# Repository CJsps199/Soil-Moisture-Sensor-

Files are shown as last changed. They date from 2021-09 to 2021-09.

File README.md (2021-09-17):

# Soil-Moisture-Sensor-
Soil Moisture sensor utilizing MCCI LMIC Library for LoRaWan© &amp; Chirpstack Network Server

# FOR SINGLE CHANNEL GATEWAY ONLY
Gateway & Sensor Node code.
Tweaked for my requirements.
# No Frequency Hopping.
# CAUTION
# NON "REGULATORY"
# USE AT OWN RISK
# Change each node's TX interval to best avoid conflict in receival on Gateway side

# Utilization of the great ChirpStack Network Server.
https://github.com/brocaar/chirpstack-network-server. (Thanks to Brocaar for this).

Using ESP8266 or ESP12F for the Gateway
Using Atmega 328P

See Eagle Drawings for compact Design of Sensor Node. +- 7cm x 4cm x 2cm.
Including MPPT Solar Charger CHIP. 
LiPo Battery Charger & Protection Circuit.

Gateway Drawing to come...

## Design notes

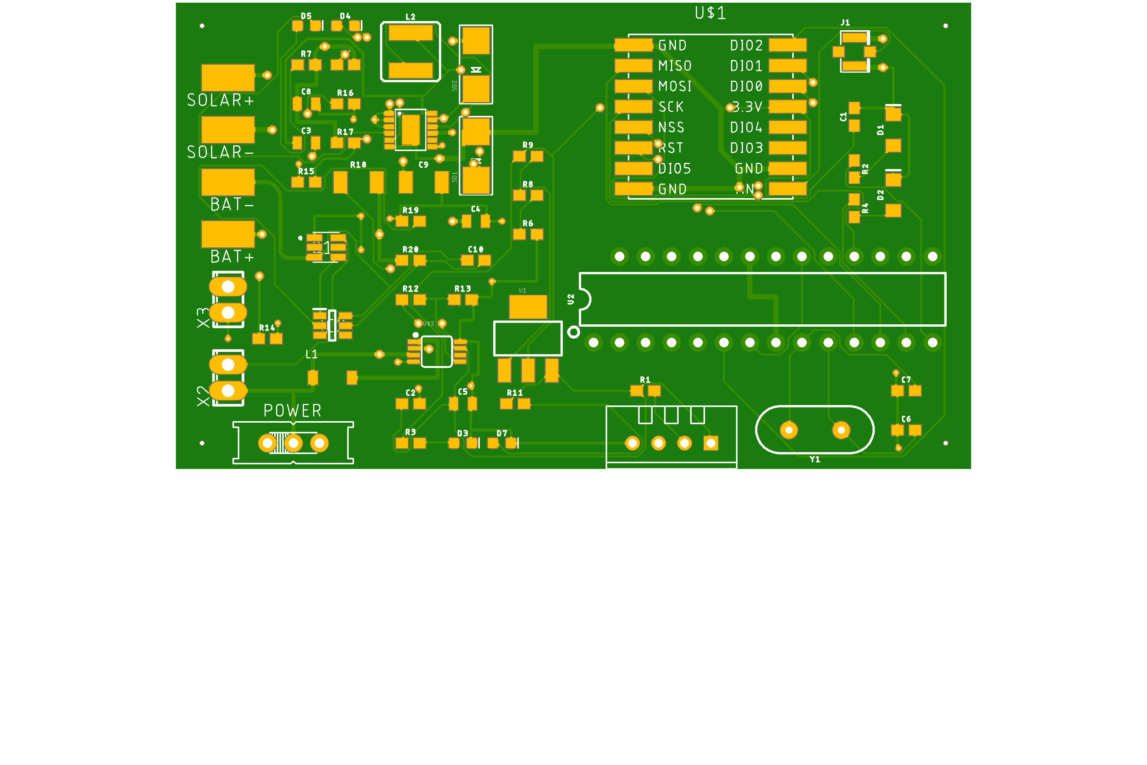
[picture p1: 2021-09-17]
Eagle/projects/Lora Node/Lora Node SM01 V1.0.png

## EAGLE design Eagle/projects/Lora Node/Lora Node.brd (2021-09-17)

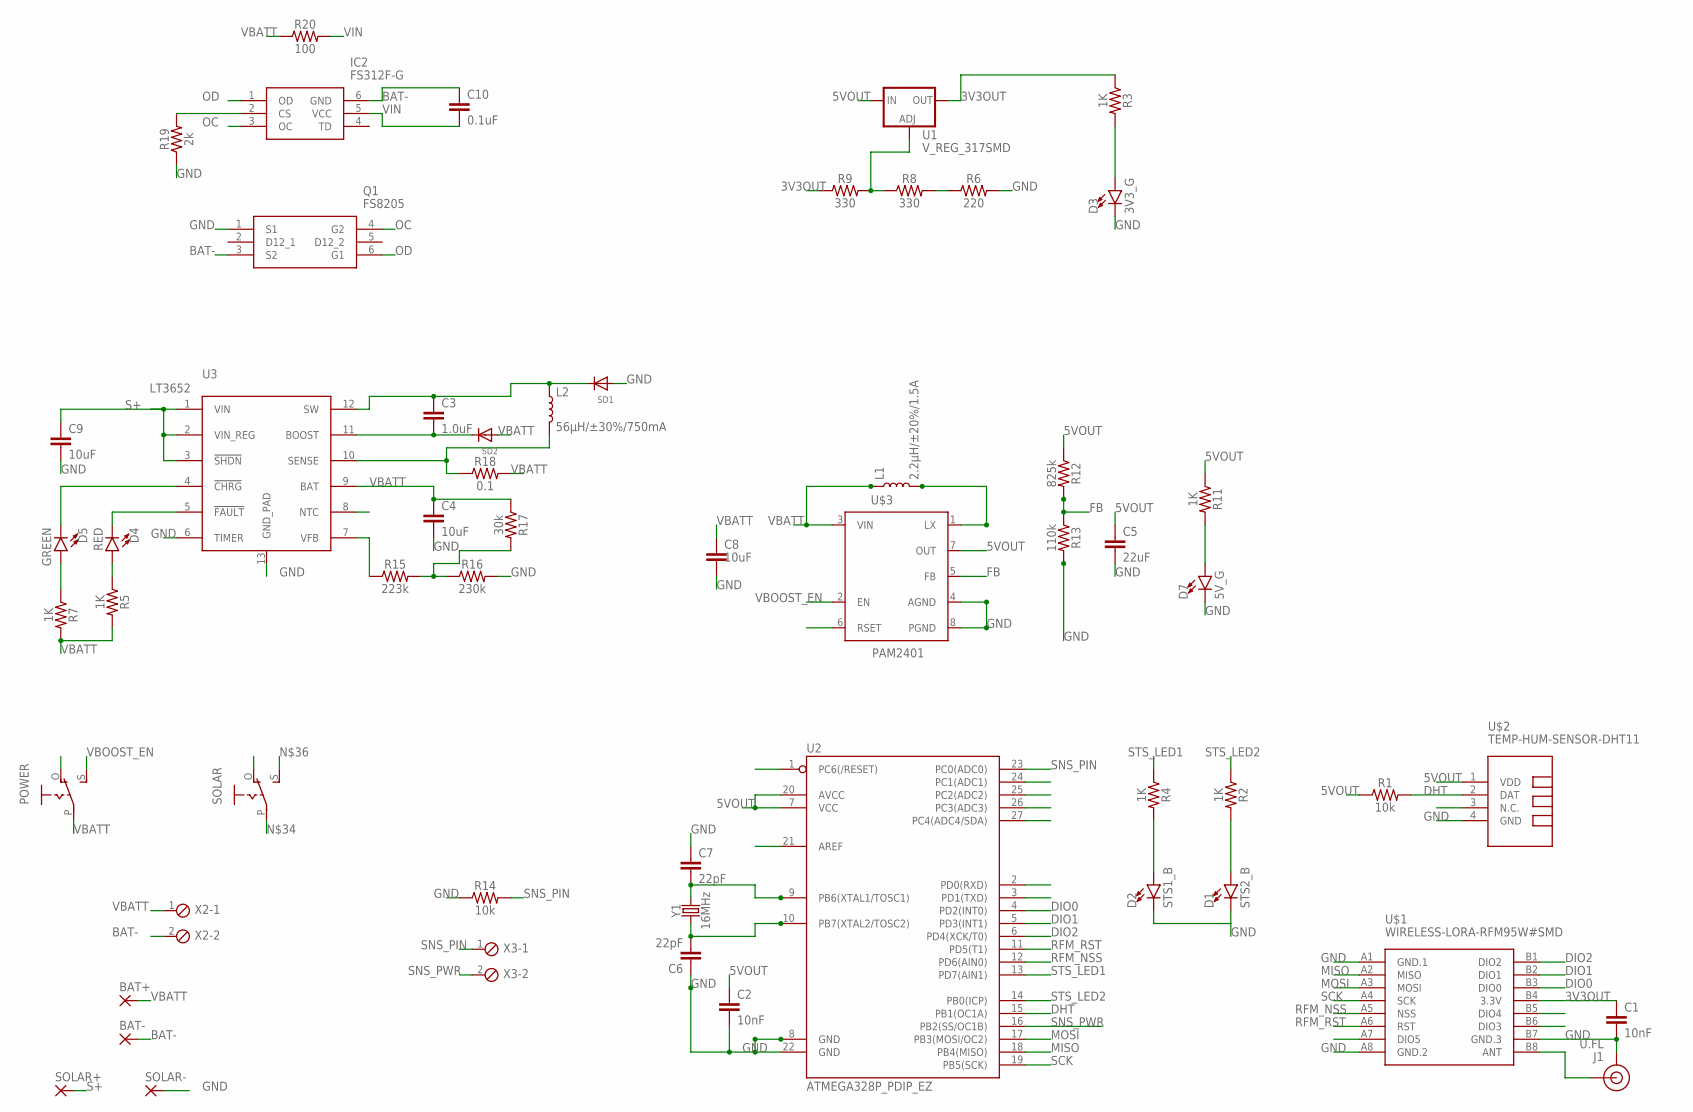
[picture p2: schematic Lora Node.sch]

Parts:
BAT+: SMD5; SMD2,54-5,08
BAT-: SMD5; SMD2,54-5,08
C1, C2: 10nF; 0603
C3: 1.0uF; 0805
C4, C8: 10uF; 0805
C5: 22uF; 0805
C6, C7: 22pF; 0603
C9: 10uF; 1210
C10: 0.1uF; 0603
D1: STS2_B; LED-1206
D2: STS1_B; LED-1206
D3: 3V3_G; LED-0603
D4: RED; LED-0603
D5: GREEN; LED-0603
D7: 5V_G; LED-0603
IC2: FS312F-G; SOT95P280X145-6N
J1: U.FL
L1: 2.2µH/±20%/1.5A; INDUCTOR_2.2UH
L2: 56µH/±30%/750mA; CR54
POWER: EG1218S; EG1218
Q1: FS8205
R1, R14: 10k; 0603
R2, R3, R4, R5, R7, R11: 1K; 0603
R6: 220; 0603
R8, R9: 330; 0603
R12: 825k; 0603
R13: 110k; 0603
R15: 223k; 0603
R16: 230k; 0603
R17: 30k; 0603
R18: 0.1; 1210
R19: 2k; 0603
R20: 100; 0603
SD1, SD2: DIODESMA; SMADIODE
SOLAR: EG1218S; EG1218
SOLAR+: SMD5; SMD2,54-5,08
SOLAR-: SMD5; SMD2,54-5,08
U1: V_REG_317SMD; SOT223
U2: ATMEGA328P_PDIP_EZ; DIP28-SIMON-KIT
U3: LT3652; MSOP-12_GND
U$1: WIRELESS-LORA-RFM95W#SMD
U$2: TEMP-HUM-SENSOR-DHT11
U$3: PAM2401; MSOP8
X2, X3: MPT2; 2POL254
Y1: 16MHz; HC49US

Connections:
3V3OUT: C1.1, R3.1, R9.1, U1.2 (OUT), U$1.B4 (3.3V)
5VOUT: C2.1, C5.1, R1.1, R11.1, R12.1, U1.3 (IN), U2.7 (VCC), U2.20 (AVCC), U$2.1 (VDD), U$3.7 (OUT)
BAT-: BAT-.1, C10.1, IC2.6 (GND), Q1.3 (S2), X2.2
DHT: R1.2, U2.15 (PB1(OC1A)), U$2.2 (DAT)
DIO0: U2.4 (PD2(INT0)), U$1.B3 (DIO0)
DIO1: U2.5 (PD3(INT1)), U$1.B2 (DIO1)
DIO2: U2.6 (PD4(XCK/T0)), U$1.B1 (DIO2)
FB: R12.2, R13.1, U$3.5 (FB)
GND: C1.2, C2.2, C4.2, C5.2, C6.1, C7.1, C8.2, C9.2, D1.C, D2.C, D3.C, D7.C, J1.1 (GND), J1.2 (GND), Q1.1 (S1), R6.2, R13.2, R14.1, R16.2, R19.1, SD1.A, SOLAR-.1, U2.8 (GND), U2.22 (GND), U3.6 (TIMER), U3.13 (GND_PAD), U$1.A1 (GND.1), U$1.A8 (GND.2), U$1.B7 (GND.3), U$2.4 (GND), U$3.4 (AGND), U$3.8 (PGND)
MISO: U2.18 (PB4(MISO)), U$1.A2 (MISO)
MOSI: U2.17 (PB3(MOSI/OC2)), U$1.A3 (MOSI)
unnamed: C7.2, U2.9 (PB6(XTAL1/TOSC1)), Y1.2
unnamed: C6.2, U2.10 (PB7(XTAL2/TOSC2)), Y1.1
unnamed: D7.A, R11.2
unnamed: D5.A, R7.1
unnamed: D3.A, R3.2
unnamed: D2.A, R4.2
unnamed: D1.A, R2.2
unnamed: D4.A, R5.1
unnamed: D5.C, U3.4 (!CHRG)
unnamed: D4.C, U3.5 (!FAULT)
unnamed: C3.1, L2.P$1 (1), SD1.C, U3.12 (SW)
unnamed: C3.2, SD2.C, U3.11 (BOOST)
unnamed: IC2.2 (CS), R19.2
unnamed: L2.P$2 (2), R18.1, U3.10 (SENSE)
unnamed: R15.1, U3.7 (VFB)
unnamed: R15.2, R16.1, R17.2
unnamed: J1.FEED (SIGNAL), U$1.B8 (ANT)
unnamed: R6.1, R8.2
unnamed: L1.P$2 (2), U$3.1 (LX)
unnamed: R8.1, R9.2, U1.1 (ADJ)
OC: IC2.3 (OC), Q1.4 (G2)
OD: IC2.1 (OD), Q1.6 (G1)
RFM_NSS: U2.12 (PD6(AIN0)), U$1.A5 (NSS)
RFM_RST: U2.11 (PD5(T1)), U$1.A6 (RST)
S+: C9.1, SOLAR+.1, U3.1 (VIN), U3.2 (VIN_REG), U3.3 (!SHDN)
SCK: U2.19 (PB5(SCK)), U$1.A4 (SCK)
SNS_PIN: R14.2, U2.23 (PC0(ADC0)), X3.1
SNS_PWR: U2.16 (PB2(SS/OC1B)), X3.2
STS_LED1: R4.1, U2.13 (PD7(AIN1))
STS_LED2: R2.1, U2.14 (PB0(ICP))
VBATT: BAT+.1, C4.1, C8.1, L1.P$1 (1), POWER.P, R5.2, R7.2, R17.1, R18.2, R20.1, SD2.A, U3.9 (BAT), U$3.3 (VIN), X2.1
VBOOST_EN: POWER.S, U$3.2 (EN)
VIN: C10.2, IC2.5 (VCC), R20.2

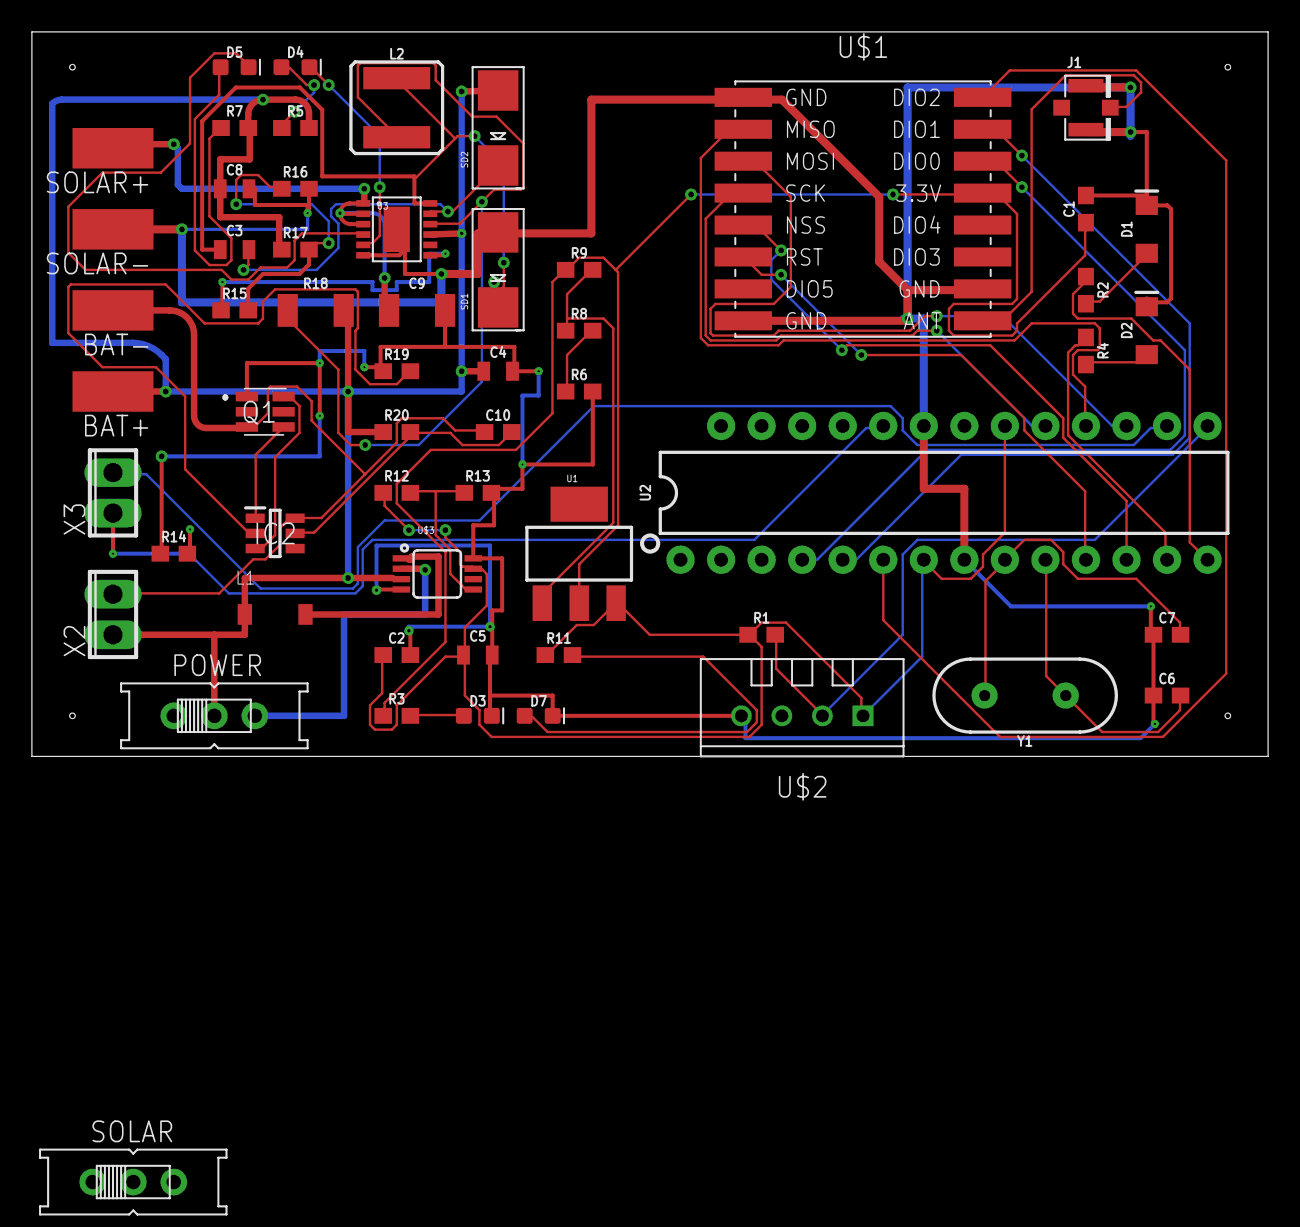
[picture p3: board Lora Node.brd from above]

Board: 2 copper layers, 77.5 x 45.4 mm, 57 parts (0 on the bottom side), 44 nets.

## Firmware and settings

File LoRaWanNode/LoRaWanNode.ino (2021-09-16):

/*******************************************************************************
 * Copyright (c) 2015 Thomas Telkamp and Matthijs Kooijman
 *
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
 * This example sends a valid LoRaWAN packet with payload "Hello,
 * world!", using frequency and encryption settings matching those of
 * the The Things Network.
 *
 * This uses ABP (Activation-by-personalisation), where a DevAddr and
 * Session keys are preconfigured (unlike OTAA, where a DevEUI and
 * application key is configured, while the DevAddr and session keys are
 * assigned/generated in the over-the-air-activation procedure).
 *
 * Note: LoRaWAN per sub-band duty-cycle limitation is enforced (1% in
 * g1, 0.1% in g2), but not the TTN fair usage policy (which is probably
 * violated by this sketch when left running for longer)!
 *
 * To use this sketch, first register your application and device with
 * the things network, to set or generate a DevAddr, NwkSKey and
 * AppSKey. Each device should have their own unique values for these
 * fields.
 *
 * Do not forget to define the radio type correctly in config.h.
 *
 *******************************************************************************/

#include <lmic.h>
#include <hal/hal.h>
#include <SPI.h>
#include <DHT.h>
#include <CayenneLPP.h>
#include <LowPower.h>


boolean sleep_counter = 0;

CayenneLPP lpp(51);





// LoRaWAN NwkSKey, network session key
// This is the default Semtech key, which is used by the early prototype TTN
// network.
static const PROGMEM u1_t NWKSKEY[16] = { 0xF0, 0xFF, 0x25, 0x4F, 0x6B, 0x0D, 0x74, 0x2D, 0x84, 0x17, 0x48, 0xEF, 0x6B, 0xD4, 0xBB, 0x42 };

// LoRaWAN AppSKey, application session key
// This is the default Semtech key, which is used by the early prototype TTN
// network.
static const u1_t PROGMEM APPSKEY[16] = { 0x85, 0x97, 0x8D, 0xF1, 0x2B, 0x9F, 0xA7, 0xC0, 0x94, 0x2D, 0xEF, 0xEA, 0xED, 0x4B, 0x47, 0xA1 };

// LoRaWAN end-device address (DevAddr)
static const u4_t DEVADDR = 0x26061493 ; // <-- Change this address for every node!

// These callbacks are only used in over-the-air activation, so they are
// left empty here (we cannot leave them out completely unless
// DISABLE_JOIN is set in config.h, otherwise the linker will complain).
//void os_getArtEui (u1_t* buf) { }
//void os_getDevEui (u1_t* buf) { }
//void os_getDevKey (u1_t* buf) { }

static uint8_t payload[8];
static osjob_t sendjob;

// Schedule TX every this many seconds (might become longer due to duty
// cycle limitations).
const unsigned TX_INTERVAL = 6;

// Pin mapping
const lmic_pinmap lmic_pins = {
    .nss = 6,
    .rxtx = LMIC_UNUSED_PIN,
    .rst = 5,
    .dio = {2, 3, 4},
};

DHT dht(9, DHT11);

void onEvent (ev_t ev) {
    
    switch(ev) {
   
        case EV_TXCOMPLETE:
//            Serial.println("tx complete");
           
            // Schedule next transmission
            os_setTimedCallback(&sendjob, os_getTime()+sec2osticks(TX_INTERVAL), do_send);
             
            break;
       
}
}

void do_send(osjob_t* j){
//while (!Serial);
// Serial.println("starting job");
    

    // Check if there is not a current TX/RX job running
   if (LMIC.opmode & OP_TXRXPEND) {
        delay(50);
        
   } else {

    if (sleep_counter == 1){
//    Serial.println("going to sleep");
    for (byte i = 0; i <= 6; i++){
      
      LowPower.powerDown(SLEEP_8S, ADC_OFF, BOD_OFF);
      LowPower.powerDown(SLEEP_8S, ADC_OFF, BOD_OFF);
      LowPower.powerDown(SLEEP_8S, ADC_OFF, BOD_OFF);
      LowPower.powerDown(SLEEP_8S, ADC_OFF, BOD_OFF);
      LowPower.powerDown(SLEEP_4S, ADC_OFF, BOD_OFF);
      
      }
      delay(50);
//      Serial.println("Waking Up");
    } 
   
    sleep_counter = 1;
    

    float temperature = dht.readTemperature();
    
        

        // read the humidity from the DHT22
    byte rHumidity = dht.readHumidity();

     int BatR = analogRead(A1);
float BatV = BatR * 0.00499;   
        
    digitalWrite(10, HIGH);     
    delay(5);
    
    byte SoilMoistPercent = map(analogRead(A0), 0, 1023, 0, 100);

    digitalWrite(10, LOW);

    delay(5);

       
    lpp.reset();
        
    lpp.addTemperature(1, temperature);
    lpp.addRelativeHumidity(2, rHumidity);
    lpp.addAnalogInput(3, SoilMoistPercent);
    lpp.addAnalogInput(4, BatV);
      
        // Prepare upstream data transmission at the next possible time.
    LMIC_setTxData2(1, lpp.getBuffer(), lpp.getSize(), 0);
//      Serial.println("data set");  
    }
    // Next TX is scheduled after TX_COMPLETE event.
}


void setup() {
  pinMode(13, OUTPUT);
  pinMode(10, OUTPUT);
//   Serial.begin(115200);
    dht.begin();
//    Serial.println("starting");
delay(100);
    

    // LMIC init
    os_init();
    // Reset the MAC state. Session and pending data transfers will be discarded.
    LMIC_reset();

    // Set static session parameters. Instead of dynamically establishing a session
    // by joining the network, precomputed session parameters are be provided.
    #ifdef PROGMEM
    // On AVR, these values are stored in flash and only copied to RAM
    // once. Copy them to a temporary buffer here, LMIC_setSession will
    // copy them into a buffer of its own again.
    uint8_t appskey[sizeof(APPSKEY)];
    uint8_t nwkskey[sizeof(NWKSKEY)];
    memcpy_P(appskey, APPSKEY, sizeof(APPSKEY));
    memcpy_P(nwkskey, NWKSKEY, sizeof(NWKSKEY));
    LMIC_setSession (0x13, DEVADDR, nwkskey, appskey);
    #else
    // If not running an AVR with PROGMEM, just use the arrays directly
    LMIC_setSession (0x13, DEVADDR, NWKSKEY, APPSKEY);
    #endif

    #if defined(CFG_eu868)
    // Set up the channels used by the Things Network, which corresponds
    // to the defaults of most gateways. Without this, only three base
    // channels from the LoRaWAN specification are used, which certainly
    // works, so it is good for debugging, but can overload those
    // frequencies, so be sure to configure the full frequency range of
    // your network here (unless your network autoconfigures them).
    // Setting up channels should happen after LMIC_setSession, as that
    // configures the minimal channel set.
    // NA-US channels 0-71 are configured automaticall

    LMIC_setupChannel(0, 868100000, DR_SF7,  BAND_CENTI);      // g-band
    
    // TTN defines an additional channel at 869.525Mhz using SF9 for class B
    // devices' ping slots. LMIC does not have an easy way to define set this
    // frequency and support for class B is spotty and untested, so this
    // frequency is not configured here.
    #elif defined(CFG_us915)
    // NA-US channels 0-71 are configured automatically
    // but only one group of 8 should (a subband) should be active
    // TTN recommends the second sub band, 1 in a zero based count.
    // https://github.com/TheThingsNetwork/gateway-conf/blob/master/US-global_conf.json
    LMIC_selectSubBand(1);
    #endif

    // Disable link check validation
    LMIC_setLinkCheckMode(0);

    // TTN uses SF9 for its RX2 window.
    LMIC.dn2Dr = DR_SF7;

    // Set data rate and transmit power for uplink (note: txpow seems to be ignored by the library)
    LMIC_setDrTxpow(DR_SF7,20);

    // Start job
    do_send(&sendjob);
    
}

void loop() {
    unsigned long now;
    now = millis();
    if ((now & 512) != 0) {
      digitalWrite(13, HIGH);
    }
    else {
      digitalWrite(13, LOW);
    }
  
    os_runloop_once();
    
}

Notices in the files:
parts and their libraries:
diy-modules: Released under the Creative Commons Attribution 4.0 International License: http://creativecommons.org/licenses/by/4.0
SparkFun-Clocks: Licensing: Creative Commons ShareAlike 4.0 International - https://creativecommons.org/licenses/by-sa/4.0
